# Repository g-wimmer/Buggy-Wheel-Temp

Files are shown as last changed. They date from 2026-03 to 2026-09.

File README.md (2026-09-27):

# Polyurethane Internal Measurement Probe
 
A battery-powered, Arduino-based temperature probe that fits within the spokes of a buggy wheel to measure heat loss data, built to quantify how well fairings and fairing liner materials (mylar, heat tape) retain wheel heat during a roll.
 
## Context
 
Many buggy teams heat their wheels for better grip and speed on the hills, using various methods (floating, shielding) to retain that heat before the start. Fringe buggies are unique in that most of the fleet uses fairings to shield the wheels, which is presumed to help with both aerodynamics and heat retention. This project set out to quantify that benefit and determine whether lining the fairings with mylar or heat tape provides a meaningful improvement.
 
## The Problem
 
Initial testing was done on a stationary buggy: lifting it up, installing the heated wheels, spinning them manually, and measuring temperature at intervals with an infrared thermometer. This approach had several issues:
 
- No continuous stream of temperature data
- No way to test heated wheels on a buggy actually rolling
- Required removing the fairing covers to get a reading
- The IR thermometer sometimes picked up heat signals from the rim or other components, muddying results
What was actually needed: a device that continuously measures wheel temperature while storing the results, fits inside the fairings without interfering with the wheel, brakes, or steering, and can survive the wheels coming straight out of the heater at up to 170°F.
 
## Design
 
**Constraints:** the fairings leave almost no clearance. The only viable free space is between the spokes of the rim — roughly 1.5-2 cubic inches. Because the wheel spins, batteries, sensors, and the microprocessor all have to live in that same space; there's no routing power or data elsewhere without a slip ring or modifying the shell.
 
**Microprocessor:** Arduino Pro Mini 3.3V — small enough to fit, and the 3.3V version means the device can run on common coin cells without needing the extra clock speed of the 5V version.
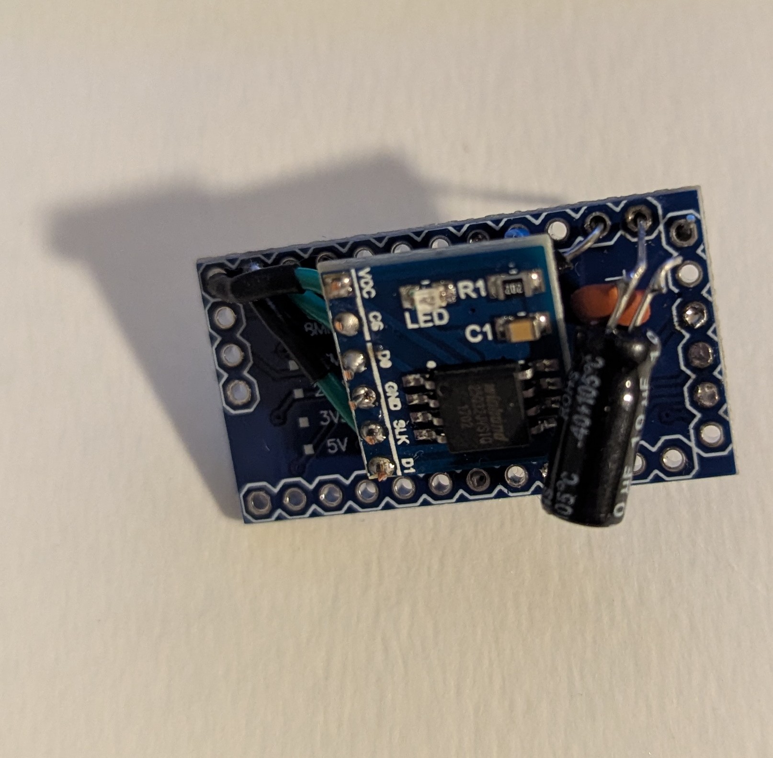
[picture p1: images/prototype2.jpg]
Prototype of the arduino with its flash memory and caps
*Prototype with the arduino, flash memory and capacitors wired*
 
**Power:** Two CR2032 coin cells in series (~6V) feeding the Arduino's voltage regulator. A single CR2032 was tried first (it would've fit in one gap between spokes), but in practice it only supplies ~3.0-3.1V, which isn't enough for the regulator, and skipping the regulator risks brownouts as the cell heats up and its voltage sags — plus the flash module's peak current draw exceeds what one cell can provide. A ceramic capacitor smooths power, and 10 µF electrolytic capacitors help with voltage dips during flash writes. Only lithium primary cells are used — LiPo batteries would combust at these operating temperatures, while lithium primary cells are rated past 200°F, making them safer. To ease the strain on the batteries, the program powers off all unncessary components of the Arduino and makes use of power saving libraries.
 
**Storage:** No good way to transmit readings live off a moving buggy, so data is stored on-device and pulled off afterward. Arduino RAM and EEPROM are both too small/limited for this (EEPROM tops out around 40 datapoints and has a limited write life), and a micro-SD rated for these temperatures would be costly. Settled on a 32MB SPI flash module — datapoints buffer in RAM and flush to flash periodically, then get pulled off over serial USB. EEPROM is used to save a pointer to the most recent batch of data in the flash.
 
**Measurement:** A 10kΩ thermistor paired with a 10kΩ resistor in a voltage divider. The Arduino reads the analog voltage and runs the Steinhart-Hart equation to get a Fahrenheit reading. The probe can be taped to the side of the wheel with reflective heat tape, or seated in a small drilled hole in the polyurethane.
 
**Case:** A 3D-modeled case sized to fit snugly between the spokes. Common filaments like PLA and PETG have glass transition temperatures too close to (or below) 170°F to be viable, so the case is printed in Polymaker PA6-CF (carbon-fiber-reinforced nylon) for its much higher heat deflection temperature. Zip-tie holes secure it against vibration at buggy speeds up to 40mph with no suspension damping. Electronics are potted in a 2-part silicone compound (McMaster-Carr 74965A52) chosen for its gel-like consistency, which wicks under the heat shrink to fully envelope the solder joints.
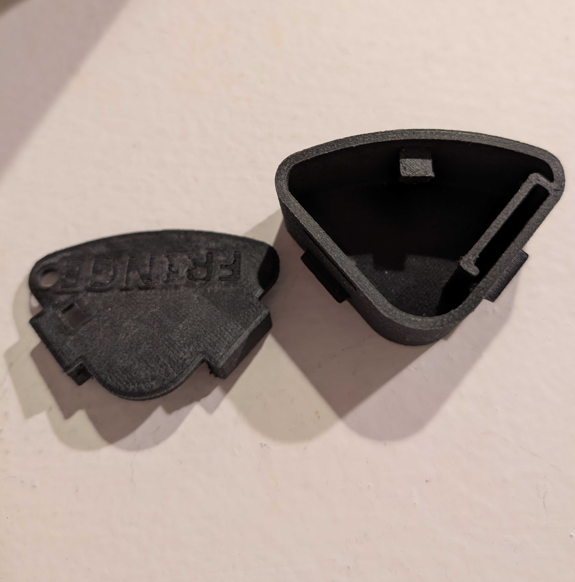
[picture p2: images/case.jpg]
Case and lid
*Case and its lid*

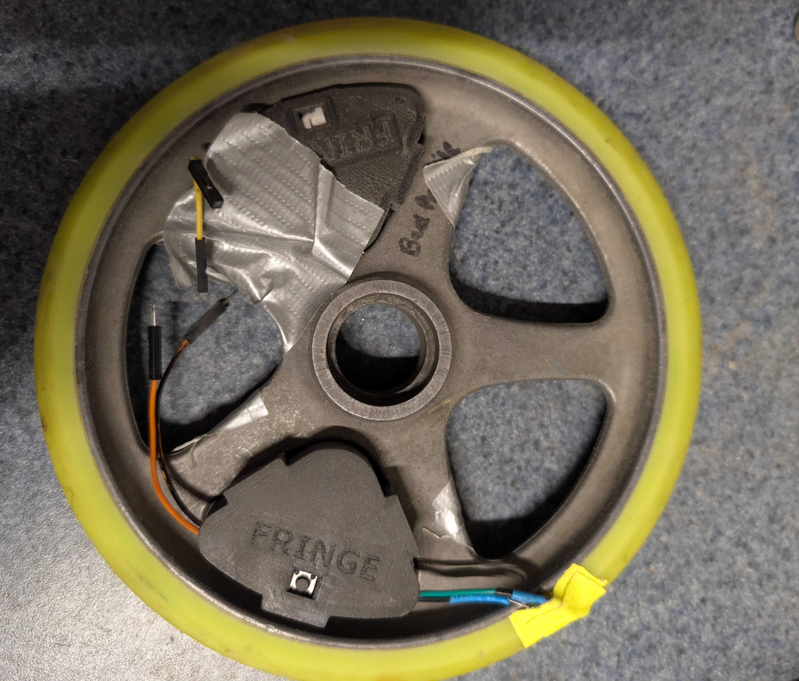
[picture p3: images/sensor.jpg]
Probe and power pack attached to a wheel with some duct tape to limit rattling
*Probe and power pack attached to a wheel with some extra duct tape to limit rattling*

## How It Works

Arduino code is located at [wheeltemp/wheeltemp.ino](wheeltemp/wheeltemp.ino)

Each datapoint is a temperature/timestamp pair — an unsigned 8-bit integer (0-255°F) and an unsigned 16-bit timestamp (0-65536), well within the expected temperature range of the wheels.
 
The probe is controlled by a single button:
- **Short press** → starts a test: reads the thermistor once per second, converts to Fahrenheit via Steinhart-Hart, and buffers the results, flushing to flash as the buffer fills or the test ends.
- **Long press (4+ seconds)** → dumps all stored data over UART serial to a connected PC.
## Testing
 
Control tests were run by mounting the wheel on an open-air frame and spinning it with a belt sander to simulate the road. The same setup was then used with the wheel mounted to the buggy, to isolate the effect of the fairing, fairing cover, and heat tape at matching speeds.

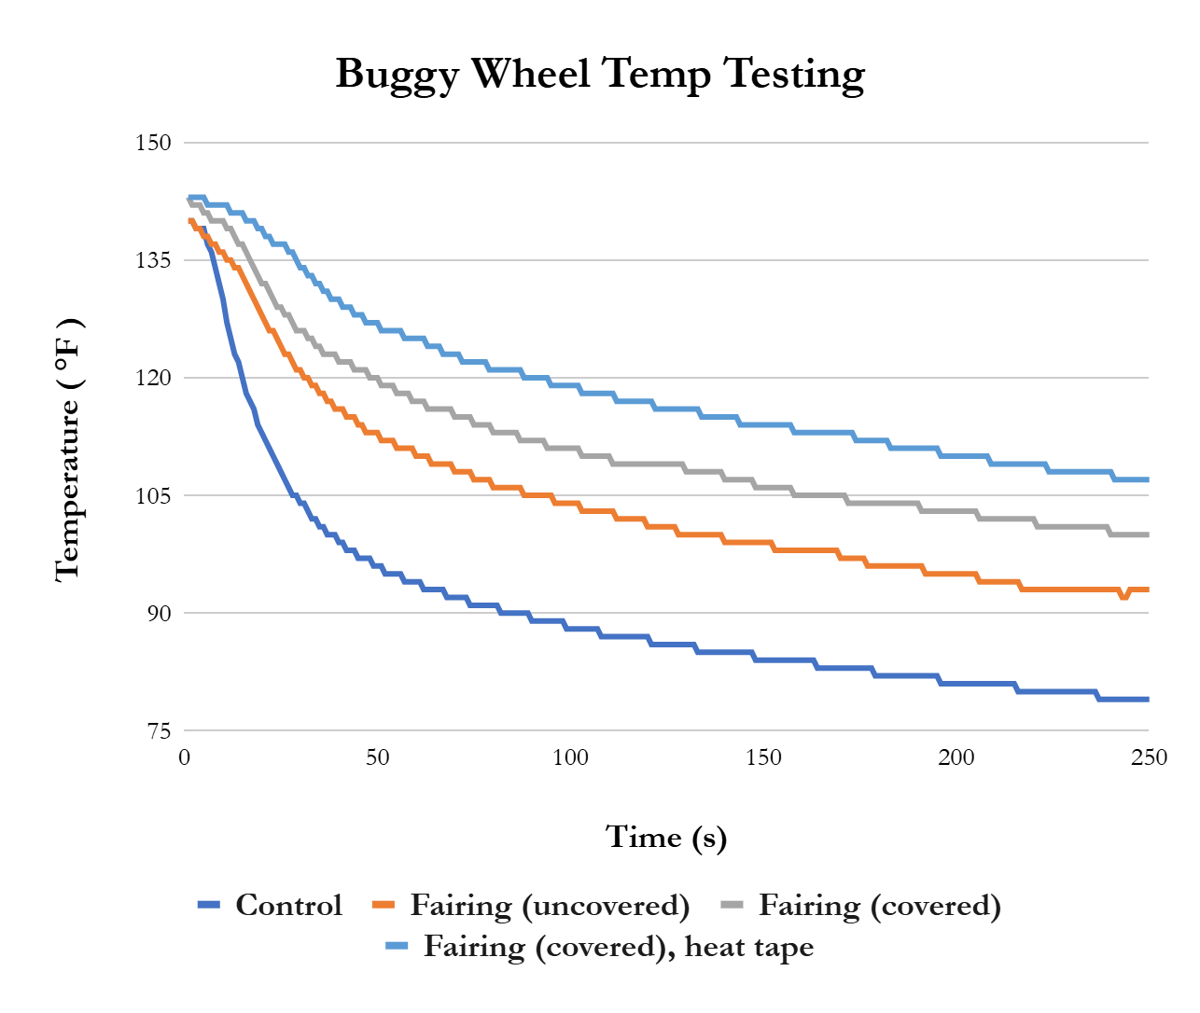
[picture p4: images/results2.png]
Results graph
*Temperature Graph*
 
It is evident that without any coverings, the wheels lose temperature rapidly. Each additional heat retention method's improvements are clearly visible across the 250 second test. This provides conclusive evidence that the heat retention methods that have been used on Fringe buggies have a quantifiable impact on the wheels.

## Usage
 
1. Seat the battery case and probe case between the wheel's spokes and snap the lids on to secure them.
   - Optionally thread a ziptie through the opening in the probe lid and case to wrap around the spoke.
2. Connect the battery pack to the probe.
   - **⚠️ Black (battery, negative) → black (probe). Yellow (battery) → orange (probe).** Wiring this wrong will permanently kill the probe.
3. Press the probe's button (**do not hold longer than 4 seconds**) to start recording.
4. When the run is done, connect the probe to the USB serial device:
   - Probe red → USB blue, probe blue → USB green, probe yellow → USB red, probe black (ground) → USB orange, probe orange (raw power) → USB yellow.
   - **⚠️ Incorrect ground/power connection here will also permanently kill the probe.**
   - These wire colors are specific to the serial connector left with the device.
5. Open a serial connection at 9600 baud (e.g. PuTTY) on the device's COM port.
   - If gibberish is showing up on the TTL, try halving the baud rate to 4800.
6. Hold the probe's button for 4+ seconds to dump the stored measurements to the serial connection.
   - Pasting the output into a text file and running the [printplot.py](printplot.py) program can be used to quickly view the data.

## Future Improvements
 
- **Calibration:** the Steinhart-Hart constants currently used are generic for the 10kΩ/10kΩ pair rather than calibrated for this specific setup. Not critical for measuring relative thermal decay, but would improve absolute accuracy.
- **Case fit:** the current case clips on and relies on protruding tabs to stay seated in the spokes. A case that molds more closely to the spoke shape would reduce rattling and give a more secure, less rim-specific fit — though a universal design will always be a tradeoff against rim-to-rim variation.

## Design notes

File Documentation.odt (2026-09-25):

Polyurethane Internal Measurement Probe

By Gabriel Wimmer

# Context

Many buggy teams heat their wheels to allow for better grip and speed throughout the hills. Different processes of holding the buggy above the ground prior to start (floating) or shielding the wheels before the starting time are employed to try and retain as much heat as possible. Fringe buggies are unique in that most of the buggies in their fleet have fairings to help shield their wheels. This provides aerodynamics benefits and it is presumed that the fairings (along with the fairing coverings) help retain heat. This project’s goal is to quantify the benefit of the fairing’s ability to retain heat and to determine if lining the insides with mylar or heat tape provide meaningful benefits.

# Objectives

The main goal of the project is to reliably measure the loss of heat from the buggy’s wheels to determine the efficacy of fairings and fairing liner materials. We have currently performed tests on a stationary buggy by lifting it up, installing the heated wheels and manually spinning it, measuring temperatures with an infrared thermometer at different intervals. This does not provide a continuous stream of temperature information and doesn’t allow for testing heated wheels on a buggy rolling on the ground. It also requires removing the fairing covers to get an accurate reading. The infrared thermometer also appears to detect heat signals from the rim or other components in the fairings, sometimes muddying the results.

Ideally, we would prefer to get more temperature readings as the wheel cools down to determine the rate of cooling. We would also want to measure the temperature as the buggy rolls in a scenario that is more representative of an actual race.

To this end, we would need a device that continually measures the temperature of the wheel while storing or transmitting the results. This would require a device that fits within the fairings and that does not impede the function of the wheel, brakes or steering.

The device needs to also measure the initial temperature as the wheel comes out of the heater, meaning it must withstand temperatures up to 170F (the agreed upon max temperature for our wheel’s polyurethane).

# Proposed Solution

The internals of the fairings have very little extra clearance. To ensure that the probe will not interfere with any of these critical components, the only viable free space appears to be between the spokes of rim. Due to the spinning of the wheels, batteries, sensors and microprocessors cannot be stored elsewhere on the buggy without the use of a slipring or modification of the buggy shell. This leaves ~1.5-2 cubic inches of space to fit a measurement probe.

To accomplish this, I decided to develop a battery powered, Arduino based, temperature probe that fits within the spokes of the wheels to record the temperature of the polyurethane as the buggy rolls. The device will store the measurements for output and review afterwards.

# Design Choices

## Microprocessor

To accomplish this, I opted to use an Arduino pro Mini 3.3v. This is one of the smaller microprocessors and its dimensions just barely fit within the allotted space. I opt for the 3.3v version instead of the 5v as I do not need the extra clock speed that the 5v version has. The 3.3v version allows me to use common coin cells to power the device, preventing the need for larger batteries.

## Power

I chose to use a pair of CR2032 coin cell batteries. This is a small battery that has a diameter less than the width of the rims. It provides 3.3v DC and a peak current of ~20mA. Originally, I had desired to use a single CR2032 to power the Arduino as it would allow the probe to fit between a single gap between the spokes of the wheel. However, in testing, the CR2032 batteries only provided ~3.0-3.1v. The Arduino’s voltage controller is unable to power the device with this low of a voltage. I could skip the voltage controller and provide the coin cell’s power straight in to the Arduinos VCC but that raises more issues. As lithium batteries heat up, their voltage drops. Without going through the voltage controller, brownouts can occur that could cause permanent damage to the device. The storage solution that I use also has peak current draws that would exceed one coin cell’s peak current. This could be compensated with large capacitors, but that would defeat the point of only using one battery.

The current solution uses 2 CR2032 coin cells wired in series to provide ~6 volts to the Arduino’s voltage controller. This solution is resilient to the drops in voltage due to heat and will be able to withstand the current spikes demanded by the flash module’s writing. I also make use of a XXX uF ceramic capacitor to smooth the power and 10 uF Electrolytic capacitors to help with voltage dips when the flash memory writes.

It is crucial that Lithium Primary cells are used. A Lithium Polymer (LiPo) battery will combust at the temperatures that this probe needs to operate at. Lithium Primary cells are rated past 200F, making them a safe choice for this project.

## Storage

While on a moving buggy, there are few options to reliably transmit the readings, meaning that our only viable option is to store the temperature readings to pull off of the probe after the test is done. The RAM on an Arduino does not have sufficient space to hold a meaningful amount of [temperature, timestamp] datapoints. Arduinos also possess EEPROM that could potentially be used, but there is only 1kB of space, meaning we can only hold ~40 datapoints if we store the temperature as an 8-byte unsigned integer and the timestamp as a 16-byte unsigned integer. EEPROM can only be written a limited amount of time, reducing the longevity of the device.

I looked into using a micro-SD card as they are capable of storing large amounts of information, but to get one that can withstand the high temperatures would be very costly.

This leaves flash memory. I choose a 32MB SPI flash module as it is lightweight, space efficient and will hold more datapoints than we will likely need. The test results will be stored to flash and then can be transferred via a serial USB connection to a PC. Data points will be buffered in RAM and then written to flash to prevent needing to write to flash for every measurement.

## Measurement

I am using a 10kOhm thermistor paired with a 10kOhm resistor set up in a voltage divider to measure the temperature. The Arduino reads the voltage via an analog input pin and performs the Steinhart-Hart equation to get a Fahrenheit measurement. The probe can either be attached to the side of the wheel and taped on with reflective heat tape, or a small hole can be drilled into the polyurethane to insert the thermistor.

## Probe Case

To properly attach to the rims of the wheels, I 3d modeled a case that fits snuggly between the spokes. Many popular 3d printing materials such as PLA and PETG have glass transition temperatures below or near 170F, ruling them out as potential options. Compared to other commonly used 3d printing filaments, nylon has a relatively high heat deflection temperature. When combined with carbon fiber additives, nylon is able to withstand temperatures way beyond what this use case requires. The specific polymer used is Polymaker’s PA6 CF.

Since the buggy can reach speeds of up to 40mph and have no dampening suspensions, the device must withstand severe vibrations. The case has holes to allow for zipties to ensure firm attachment. To protect the electronics, I opted to use a 2 part silicone potting compound. I specifically chose this McMasterCarr item: 74965A52 due to its gel like consistency, hoping to allow the compound to wick under the heat shrink to envelope the solder joints within.


Figure 1: Case and its lid

# Code Summary

The code that runs on the Arduino starts by initializing key variables and data structures. As mentioned before, each datapoint is a temperature timestamp pair where the temperature is an unsigned 8-bit integer and the timestamp is an unsigned 16-bit integer. This gives us a temperature range of 0-255 Fahrenheit and a timestamp range of 0-65536. Our expected temperature readings are not expected to go past 170F, leaving us a good margin of safety.

The probe is controlled by a single button. A short press of the button will begin a testing sequence while holding the button for several seconds will begin data transfer. The testing sequence begins a loop of reading analog inputs from the thermistor and converting it to Fahrenheit via the Steinhart-Hart equation. These datapoints are saved into a buffer. After the buffer fills up, or the test ends, the buffer is written to the flash storage module. Currently, measurements are taken once per second.

The data transfer function relies on a UART serial connection to a computer. After plugging in the RX and TX pins, the Arduino can read all of the stored data from flash and print them out to a terminal on your PC for analysis.

# Testing and Results

The control for our tests was performed by mounting the wheel to an open air frame and then spinning the wheel with a belt sander to simulate the road. The following tests were done with the wheel attached to a buggy to measure the impact of the buggy’s fairing, fairing cover and heat tape. These were also spun using a belt sander at the same speeds as the control.


Figure 2: Test results

# Usage

## Quick Start

1. Put battery case and probe case in a wheel
  a. Put the lids on both to affix them to the spokes
2. Connect the power from the battery pack to the probe
  a. CRITICAL: Connect the black from the battery pack (negative) to the black wire from the probe. The yellow from the battery connects to the orange from the probe.
    i. Incorrect connection here will permanently kill the probe
3. Press the button on the probe (do not hold for longer than 4 seconds) to start recording temperatures
4. When the measurements are done, connect to the USB serial device
  a. Probe red -> usb blue, probe blue -> usb green, probe yellow -> usb red, probe black (ground) -> usb orange, probe orange (raw power) -> usb yellow
  b. Incorrect connection of the ground and power will permanently kill the probe
5. Use PUTTY to open a serial connection (baud rate 9600) on the devices comm port
6. Press the button on the probe for more than 4 seconds to dump the measurements to the serial connection

To use the probe, open both the batter pack and the probe cases and place them between the spokes of the wheels. You can then place the lids on both of the cases, ensuring that the wires for the power supply are routed through the holes in the case, along with the thermistor. Also ensure that the

# Future Improvements

## Code Improvements

There are several areas in which the code can be improved. Right now, the constants used for the Steinhart-Hart equation are general ones for the given 10kOhm resistor and 10kOhm thermistor pair. To get a more accurate Fahrenheit reading, it would be better to calibrate these constants. For the purposes of measuring the decay in thermal energy, this isn’t as critical, but would help provide more useful information.

## Probe Improvements

The case currently has a lid that clips on to the top, limiting the debris that can get into it. The clips that stick out from the case also serve to keep the case within the spokes of the wheels. Designing a case that better molds to the shape of the spokes would help prevent rattling and ensure a secure fit. Due to the slight differences in rim design, this would restrict which wheels the probe can be used on. A more robust attachment method would benefit the device greatly.

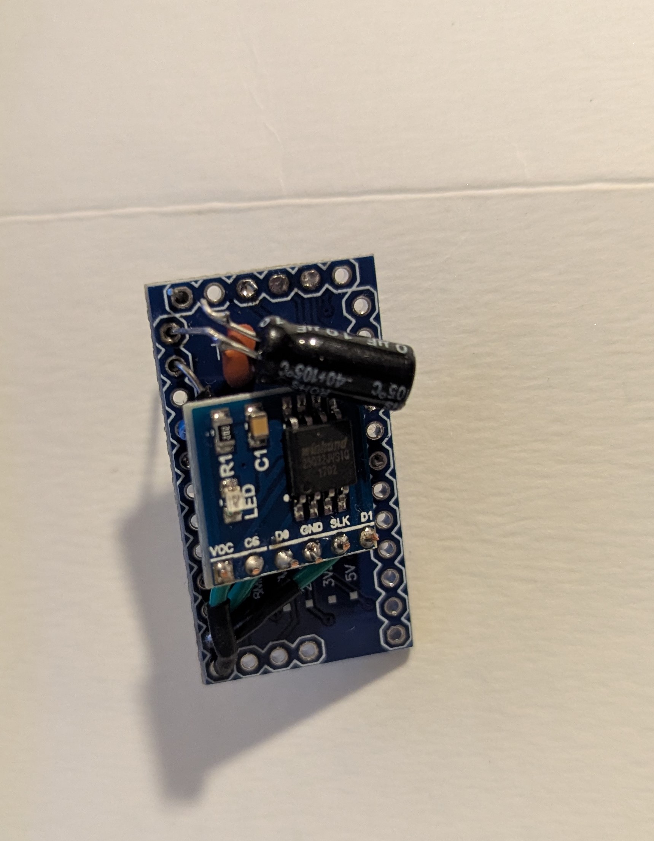
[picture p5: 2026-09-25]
images/prototype.jpg

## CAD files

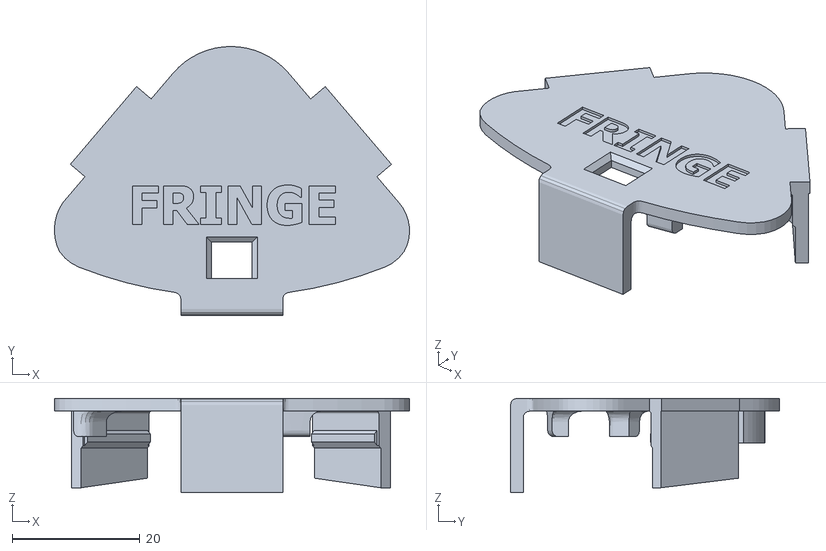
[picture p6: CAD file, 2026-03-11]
CAD/sensorlidv2.stl
55.6 x 42.2 x 14.8

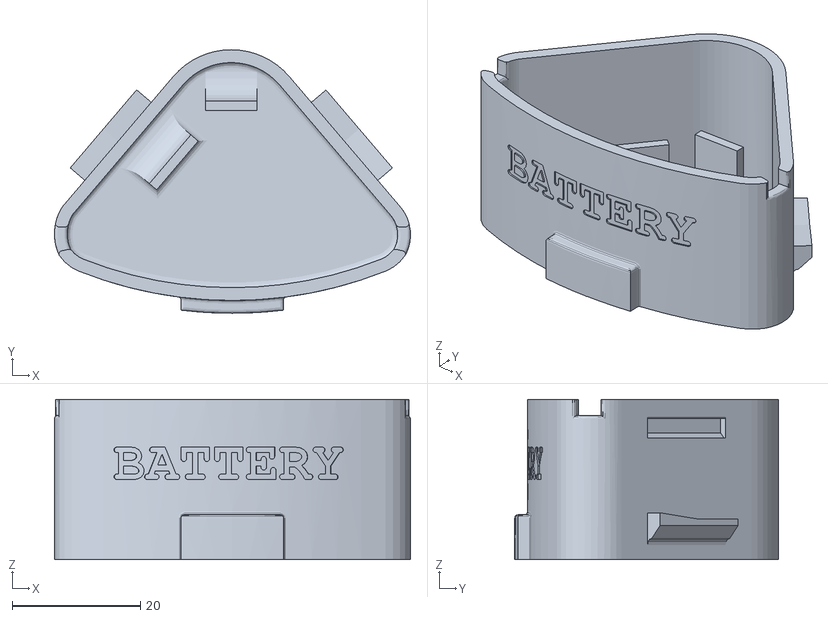
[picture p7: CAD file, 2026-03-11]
CAD/batterypack.stl
55.6 x 41.2 x 25.0

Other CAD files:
CAD/sensor.stl
CAD/batterypack.ipt
CAD/batterypacklid.ipt
CAD/sensor.ipt
CAD/sensorlid.ipt
CAD/sensorlidv2.ipt

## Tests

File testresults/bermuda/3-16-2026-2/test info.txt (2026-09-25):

5 min in egg
wheel was slightly warm going in

handheld belt sander on wheel

fairing covers on with heat tape on wheel well and cover

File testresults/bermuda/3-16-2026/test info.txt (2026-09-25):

5 mins in egg
handheld belt sander
fairing covers on with heat tape on covers and in wheel well

belt sander lost contact with the wheel for a while

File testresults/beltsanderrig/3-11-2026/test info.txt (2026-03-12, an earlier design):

belt sander wheel spinning rig
5 min in egg with room temp wheel

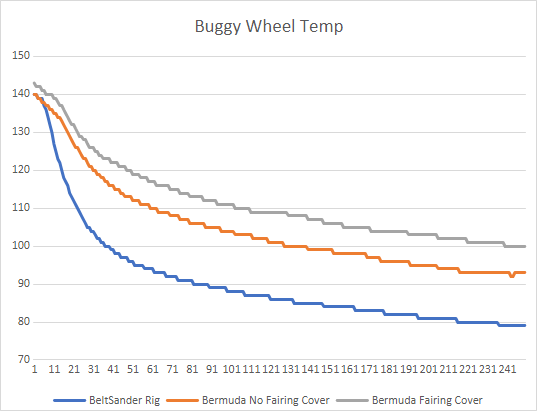
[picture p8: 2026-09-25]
images/results.png

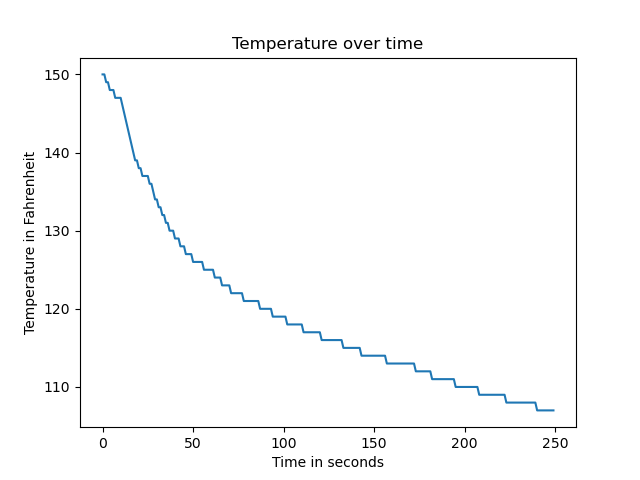
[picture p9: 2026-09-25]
testresults/bermuda/3-16-2026-2/Figure_1.png

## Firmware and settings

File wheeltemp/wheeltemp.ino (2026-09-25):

#include <LowPower.h>
#include <SPIMemory.h>
#include <avr/power.h>
#include <EEPROM.h>
//Arduino based wheel temperature probe by Gabriel Wimmer
//Measures the temperature of a buggy wheel every second using a thermistor.
//Implements several power saving techniques to extend useable lifetime.
//Data is buffered in memory before being written to flash in bursts.
//EEPROM holds pointers to each test run's data in flash.

const int thermpin = A3;
const int lightpin = 5; 
const int startbuttonpin = 2; //interrupt pin
const int senddatabuttonpin =3;
const int total_seconds = 250;
uint16_t numtest = 0;
const int eepromAddr = 0;


volatile unsigned long buttontime = 0;
volatile bool buttonPressed = false;
volatile unsigned long pressStartTime = 0;

const unsigned long DEBOUNCE_DELAY = 50; // Debounce time in milliseconds

uint32_t currentaddress = 0;

//Constants for Steinhart-Hart equation
int Vo;
float R1=10000;
float logR2, R2, T;
float c1 = .001170, c2 = .000234125, c3 = .0000000876741;



SPIFlash flash(10);

//datapoint structure to hold the time and temp
struct datapoint{
  uint16_t timestamp;
  uint8_t temp;
};

//ram buffer to hold datapoints
datapoint buffer[100]; 



void setup() {
  //Disable unncessary processes on the Arduino to save power
  power_adc_disable();
  power_timer1_disable();
  power_timer2_disable();
  power_twi_disable();

  Serial.begin(9600);
  
  delay(100);
  pinMode(lightpin, OUTPUT);
  pinMode(thermpin, INPUT);
  pinMode(startbuttonpin, INPUT_PULLUP);

  delay(100);

  if (!flash.begin()) {
    digitalWrite(lightpin, HIGH);
    Serial.println("Flash memory init error. hanging program");
    while(1);
  }
  delay(100);
  digitalWrite(lightpin, HIGH);
  attachInterrupt(digitalPinToInterrupt(startbuttonpin), buttonpressedIR, FALLING);

  Serial.println("--------------------STARTING PROGRAM--------------------");
  bool flashup = flash.powerUp();
  delay(100);
  EEPROM.get(eepromAddr, numtest); //Check EEPROM for the # of the last test conducted to find where in flash to start saving data
  if(flashup ==false){
    Serial.println("Powerup failed in setup");
  }

  delay(100);

  if(numtest <= 0 || numtest > 20){ //sanity check on the number of records that are currently in flash
    Serial.print("Resetting number of tests, num records is: ");
    Serial.println(numtest, DEC);
    Serial.println("Erasing chip, may take time");
    flash.eraseChip(); //zero out chip
    numtest = 0;
    EEPROM.put(eepromAddr, numtest);
    Serial.println("Erasing complete");
  }
  
  Serial.print("Current numtest: ");
  Serial.print(numtest, DEC);
  Serial.println();

  flash.powerDown();

  currentaddress = (numtest * total_seconds * 3);

  Serial.println("Ready - press button to start test");
  delay(200);

  digitalWrite(lightpin, LOW);

}

//Button press interrupt function that is used to interrupt the sleeping system
void buttonpressedIR(){
  static unsigned long lastInterruptTime = 0;
  unsigned long interruptTime = millis();
  if (interruptTime - lastInterruptTime > DEBOUNCE_DELAY) {
    buttonPressed = true;   // Signal main loop to handle press
    pressStartTime = interruptTime; // Record when press began
  }
  lastInterruptTime = interruptTime;
}


//Main loop that waits for a button press
void loop() {
  if(buttonPressed){
    waitForRelease();
    buttonPressed = false;
    unsigned long pressDuration = millis() - pressStartTime;
    if(pressDuration < 4000){
      Serial.println("short press, starting test");

      runtest();
    }else{
      Serial.println("long press, dumping data");
      dumptoserial();
    }
    buttonPressed = false;

  }
  Serial.println("In the main loop, waiting for a button press");
  delay(100);
  LowPower.powerDown(SLEEP_8S, ADC_OFF, BOD_OFF);

}

//Waits for the button to be released
unsigned long waitForRelease(){
  unsigned long waitstart = millis();
  unsigned long pressstart = buttontime;
  while(digitalRead(startbuttonpin) == LOW){
    if(millis() - waitstart > 14000){
      Serial.println("Button got stuck? Timeout occured in waitforrelease");
      break;
    }
    delay(10);
  }
  delay(DEBOUNCE_DELAY);
}

//Reads the temperature via the thermisitor
//Utilizes the Stienhart-Hart equation to calculate the temperature
uint8_t readtemp(){
  power_adc_enable();
  delayMicroseconds(100);
  Vo = analogRead(thermpin);
  power_adc_disable();
  R2 = R1 * (1023.0 / (float)Vo - 1.0);
  logR2 = log(R2);
  T = (1.0 / (c1 + c2*logR2 + c3*logR2*logR2*logR2));
  T = T - 273.15;
  T = (T * 9.0)/5.0 + 32.0;
  return (uint8_t) round(T);

}

//Begins a new test. Records a temperature reading every second for total_seconds
//Buffers data points in RAM and stores it in flash once the buffer is full
void runtest(){
  digitalWrite(lightpin, HIGH);
  Serial.println("Starting recording");
  uint16_t bufferIndex = 0;
  //flash.powerUp();
  delay(200);
  
  //flash.eraseSection(2+(3*total_seconds*(numtest)),3*total_seconds);
  delay(300);
  digitalWrite(lightpin, LOW);
  //flash.powerDown();
  

  for(int samplenum = 0; samplenum<total_seconds; samplenum++){

    buffer[bufferIndex].timestamp = samplenum;
    buffer[bufferIndex].temp = readtemp();
    bufferIndex++;
    if(bufferIndex >= 100) {
      writeBuffer(buffer, bufferIndex);
      bufferIndex = 0;
      delay(780); //different delay time to account for writing and flash power up time
    }else{
      LowPower.powerDown(SLEEP_1S, ADC_OFF, BOD_OFF);
    }

  }

  if(bufferIndex > 0) {//save remaining in buffer
      writeBuffer(buffer, bufferIndex);
      bufferIndex = 0;
  }
 
  numtest++;

  EEPROM.put(eepromAddr, numtest); //Update EEPROM to store the current number of tests in the flash memory


}


//Write data from the buffer to flash via spi
void writeBuffer(datapoint *buff, uint16_t num){
  flash.powerUp();
  delay(100);
  Serial.println("Writing entries to flash:");
  Serial.println(num, DEC);
  for(int i=0; i < num; i++){
    flash.writeShort(currentaddress, buffer[i].timestamp);
    flash.writeByte(currentaddress + 2, buffer[i].temp);
    currentaddress += 3;
  }
  delay(100);
  flash.powerDown();
}

//Dump the datapoints from the flash memory to serial to access them from your computer
void dumptoserial(){
  flash.powerUp();
  Serial.print("DUMPING DATA TO SERIAL. Number of tests run: ");
  Serial.println(numtest, DEC);
  for(int i = 0; i < 5; i++){
    digitalWrite(lightpin, HIGH);
    delay(100);
    digitalWrite(lightpin,LOW);
    delay(100);
  }

  uint32_t readaddr = 0; // start after number of tests
  for(int i = 0; i < numtest; i++){
    Serial.print("Test number: ");
    Serial.println(i, DEC);
    Serial.println("Timestamp (second), Temp (fahrenheit)");
    for(int n = 0; n < total_seconds; n++){
      uint16_t timestamp = flash.readShort(readaddr);
      uint8_t temp = flash.readByte(readaddr + 2);
      Serial.print(timestamp, DEC);
      Serial.print(",");
      Serial.println(temp, DEC);
      readaddr += 3;
    }

  }
  currentaddress = 0;
  Serial.println("DUMP COMPLETE, ERASING FLASH");
  flash.eraseChip();
  numtest = 0;
  delay(100);
  flash.powerDown();
  EEPROM.put(eepromAddr, numtest); 
  Serial.println("FLASH ERASED");
 
  

}

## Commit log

2025-11-06 started arduino program
2026-02-10 code mostly done, added more low power optimization
2026-02-10 added cad files
    [sensor.ipt, sensorlid.ipt]
2026-02-11 added battery lid file
    [batterypacklid.ipt]
2026-02-11 more changes to cad files
    [sensor.0001.ipt, sensor.ipt, sensorlidv2.0002.ipt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]
2026-02-11 tiny changes to lid tabs
    [sensorlidv2.0002.ipt, sensorlidv2.0003.ipt, sensorlidv2.ipt]
2026-02-11 fixed button holder
    [sensor.0001.ipt, sensor.0002.ipt, sensor.ipt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]
2026-02-12 fixed bug in how sections of memory are erased before a test
    [wheeltemp.ino]
2026-02-17 more power optimizations
2026-02-17 fixes to address offset when dumping data
    [wheeltemp.ino]
2026-02-27 changes to code for power efficiency
2026-02-27 minor changes to sensor casing for themisitor routing
    [sensor.0002.ipt, sensor.0004.ipt, sensor.ipt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]
2026-02-27 added new support tab to case to stop tilting
    [sensor.0004.ipt, sensor.0005.ipt, sensor.ipt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]
2026-02-27 changed size of new support tab
    [sensor.0005.ipt, sensor.0006.ipt, sensor.ipt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]
2026-02-27 changed size of new support tab shga]
    [sensor.0006.ipt, sensor.0007.ipt, sensor.ipt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]
2026-03-11 added tabs to hold battery in place better
    [batterypack.0001.ipt, batterypack.ipt, batterypack.stl]
2026-03-11 strengthened battery tabs
    [batterypack.0001.ipt, batterypack.0002.ipt, batterypack.ipt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]
2026-03-11 added tabs to lid to prevent shaking
    [sensorlidv2.0003.ipt, sensorlidv2.0004.ipt, sensorlidv2.ipt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]
2026-03-12 got test data on belt sander driven wheels
    [datagraph.xlsx]
2026-03-19 more data from different test runs + excel graphing them
    [datagraph.xlsx]
2026-09-25 cleaning up repo
    [batterypack.0002.ipt, batterypack.ipt, batterypack.stl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]
2026-09-27 added picture of entire device
2026-09-27 fixed sensor images
2026-10-28 cleaning cad
